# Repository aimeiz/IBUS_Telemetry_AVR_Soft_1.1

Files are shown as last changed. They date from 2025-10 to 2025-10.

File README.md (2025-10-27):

# IBUS_Telemetry_AVR_Soft_1.1
This is simple combo sensor for Flysky ADHDS2A RC systems.
Based on Arduino MiniPro 5V 16MHz , NEO6M-7M-GPS and BME280 5V modules.
It communicates with Flysky receivers i.e FS-IA6b via Sebsor IBUS port.
Prototype has been built on doublesided prototype PCB.
Elements are mounted on both side, to assure compact sensor sizes.
I attach also schematics, PCB design (Eagle / Fusion), and cabinet stls for 3D print and Gerber files to make easy order for PCB's
For more modern GPS module i.e 8M PCB require minor patching - modules have different pinout.
Major issue is, that IBUS libraries i found and used for this project, do not support block send of GPS data, so popular FX-i6X transmitter doesn't display GPS data correctly.
I am using Radiomaster TX16S 4in1 with EbgeTX 2.11.3 open source firmware and it works well. So I attach GpsInfo widget for tis system.
TO DO - electronics has additional servo port to connect to free servo channel or IBUS servo port to update Home position and altitude. It is not implement in current firmware version.
Yhe easiest way is to use servo channel, but also possible to decode IBUS servo port signal to extract servo channel which is even not covered by receiver's servo terminal.
Feel free to use, fork and modify.

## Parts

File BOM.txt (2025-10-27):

Partlist exported from C:/Users/sp5io/AppData/Local/Temp/Neutron/ElectronFileOutput/13544/sch-48b16895-195c-4b96-89e7-4660fa59e146/Bez nazwy.sch at 10/27/2025 7:45 AM

Part     Value                Device                Footprint Name          Detailed Description                                                          CATEGORY  MANUFACTURER MPN OPERATING_TEMP PART_STATUS POPULARITY ROHS_COMPLIANT SERIES SPICEPREFIX SUB-CATEGORY THERMALLOSS TYPE VOLTAGE_RATING
B1       ARDUINO_PRO_MINI     ARDUINO_PRO_MINI      ARDUINO_PRO_MINI        SparkFun Pro Mini                                                                                                                                                                                                            
C1       4700uF/6.3V          C-POL_RADIAL-11MM-DIA CAPPRD508W65D1000H1100B Capacitor Polarised - Generic                                                 Capacitor                                                                                                                                      
C2       100nF                C-US025-024X044       C025-024X044            CAPACITOR, American symbol                                                                                                          17                               C                                                       
DEBUG                         PINHD-1X2             1X02                    PIN HEADER                                                                                                                          98                                                                                       
HOME_SET                      PINHD-1X3             1X03                    PIN HEADER                                                                                                                          92                                                                                       
IBUS_IN                       PINHD-1X3             1X03                    PIN HEADER                                                                                                                          92                                                                                       
IBUS_OUT                      PINHD-1X3             1X03                    PIN HEADER                                                                                                                          92                                                                                       
R1       4.7K                 R-EU_0204/5           0204/5                  RESISTOR, European symbol                                                                                                           35                               R                                                       
R2       4.7K                 R-EU_0204/5           0204/5                  RESISTOR, European symbol                                                                                                           35                               R                                                       
R3       180K                 R-EU_0204/5           0204/5                  RESISTOR, European symbol                                                                                                           35                               R                                                       
R4       10K                  R-EU_0204/5           0204/5                  RESISTOR, European symbol                                                                                                           35                               R                                                       
U1       BME280_MODULE_5V_STD BME280_MODULE_5V_STD  BME280_MODULE_5V        BME280/BMP280 5 V I2C breakout (VIN,GND,SCL,SDA), 15×11 mm, outline tDocu(51)                                                                                                                                                
U2       NEO6M_GPS_MODULE     NEO6M_GPS_MODULE      NEO6M_GPS_MODULE                                                                                                                                                                                                                                     
UPLOAD                        PINHD-1X2             1X02                    PIN HEADER                                                                                                                          98                                                                                       
VOLTAGE                       PINHD-1X1             1X01                    PIN HEADER                                                                                                                          64

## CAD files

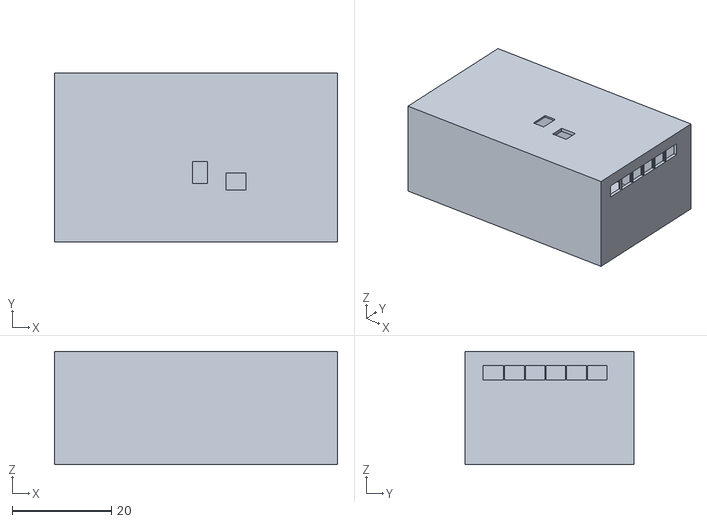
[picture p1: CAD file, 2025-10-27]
Cabinet_55x33.stl
57.0 x 34.0 x 22.8

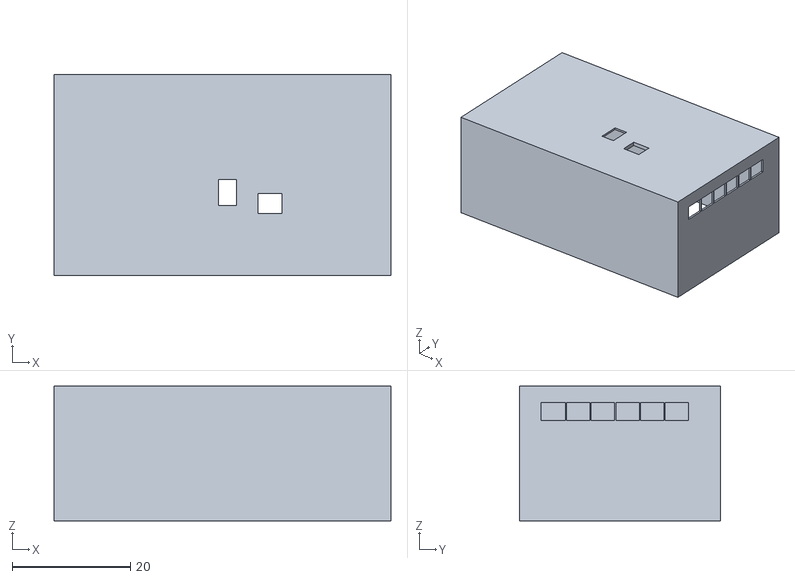
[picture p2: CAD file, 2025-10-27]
Cover_55x33.stl
57.0 x 34.0 x 22.8

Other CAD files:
IBUS GPS BME Sensor v6.f3d

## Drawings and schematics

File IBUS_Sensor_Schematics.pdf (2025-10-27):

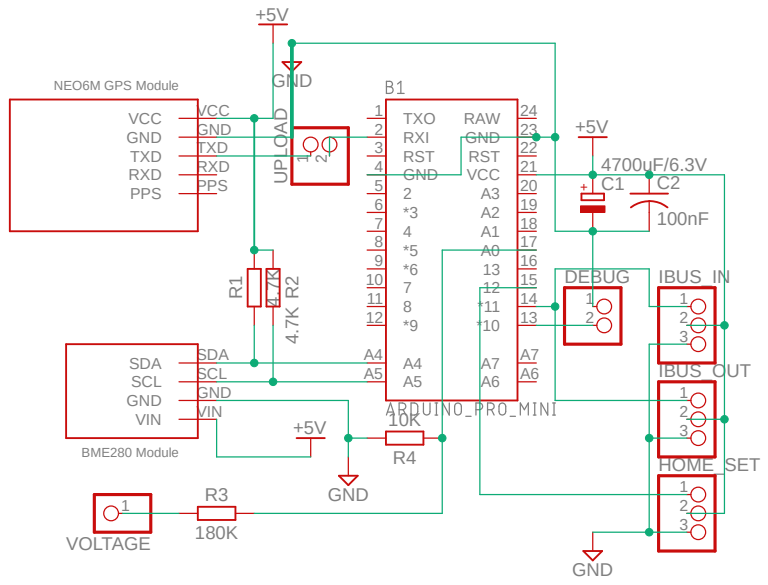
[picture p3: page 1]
GND; 20 GND 4; 23 RAW; RST 3; RST; 22 RXI 2; TXO 1; VCC; VIN; VIN GND; GND SCL; SCL SDA; SDA; BME280 Module; R² UPLOAD 1; DEBUG 1 2; IBUS_IN 1 2 3; IBUS_OUT 1 2 3; HOME_SET 1 2 3; VOLTAGE; TXD; RXD; PPS; NEO6M GPS Module

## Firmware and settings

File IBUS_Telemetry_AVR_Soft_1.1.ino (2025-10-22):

/*IBUS Combo sensor based on NEO GPS, BPS280 sensor and Arduino AVR Atmega328P module by Aimeiz 2025/10
 * Based on IBUSTelemetry library by adis1313 https://github.com/SoluTekSteam/75_IbusTelemetry_adis1313_iBUSTelemetry-Arduino
 * GPS and debug / upload serial port is shared, so assure jumper to disconnect GPS Tx pin from Arduino RX0 pin to upload code
 * DBUG Serial printous are activated by setting DEBUG_PIN to LOW state. Disable DEBUG for normal opiretion. 
 * Pullup I2C SDA, SCL lines by 4.7k resistors.
 * Install >= 1000uF/ 6.3V Low ESR capacitor on 5V supply I used 4700uF / 6.3V, and 0.1uF also, to block interferences.
 * 
 * Current version doesn't display GPS data properly on Flysky I6X transmitter due to old data format, but works well on EdgeTX (RADIOMASTER TX16S
 * See attached GpsInfo widget for EdgeTX 
 */
 
#define VERSION "IBUS Telemetry V1.1 20251018 Arduino Pro Mini ATMEGA328 Mini 5V 16MHz, BMe/BMP280 5VV NEO-6M-7M-GPS 5V"
//#define VERSION "IBUS Telemetry V1.1 20251018 Arduino Nano ATMEGA328 Mini 5V 16MHz, BMe/BMP280 5V NEO-6M-7M-GPS 5V"

#include "iBUSTelemetry.h" https://github.com/SoluTekSteam/75_IbusTelemetry_adis1313_iBUSTelemetry-Arduino
#include <Wire.h>
#include <BME280I2C.h>          // https://github.com/Seeed-Studio/Grove_BME280
#include <TinyGPS++.h>          // https://github.com/mikalhart/TinyGPSPlus

#define IBUS_PIN 11             // pin RX IBUS (PCINT na Nano)
iBUSTelemetry telemetry(IBUS_PIN);

BME280I2C bme;                  // default addr 0x76
float temperature = 0, pressure = 0, altitude = 0;
float basePressure = 1013.25;

// --- Hardware state flags ---
bool bmeAvailable = false;
bool bmeHasHumidity = false;
bool gpsAvailable = false;
uint8_t bmeType = 0;   // 0=none, 1=BMP280, 2=BME280, 3=unknown

#define gpsSerial Serial
TinyGPSPlus gps;

#define VOLTAGE_PIN A0
#define VOLTAGE_DIVIDER 23.974

#define DEBUG_PIN 10             // podłączony do GND = włącz debug
#define UPDATE_INTERVAL 500
uint32_t prevMillis = 0;

double homeLat = 0, homeLon = 0, homeAlt = 0;
bool homeSet = false;

void setup()
{
  pinMode(DEBUG_PIN, INPUT_PULLUP);
  gpsSerial.begin(9600);
  delay(2000); // czekaj na stabilizację zasilania
  if (digitalRead(DEBUG_PIN) == LOW) {
    Serial.println(F(VERSION));
  }
  Wire.begin();
  telemetry.begin();

  // Czujniki 2B
  telemetry.addSensor(IBUS_MEAS_TYPE_TEM);         // 0x01 1
  telemetry.addSensor(IBUS_MEAS_TYPE_EXTV);        // 0x03 2
  telemetry.addSensor(IBUS_MEAS_TYPE_GPS_STATUS);  // 0x0B 3
  telemetry.addSensor(IBUS_MEAS_TYPE_GPS_DIST);    // 0x14 4
  telemetry.addSensor(IBUS_MEAS_TYPE_CMP_HEAD);    // 0x08 5
  telemetry.addSensor(IBUS_MEAS_TYPE_GROUND_SPEED);// 0x13 6
  //  telemetry.addSensor(IBUS_MEAS_TYPE_GPS_FULL);	    //0xfd 7
  // Czujniki 4B
  telemetry.addSensor(IBUS_MEAS_TYPE_ALT);         // 0x83 (4B) 7
  telemetry.addSensor(IBUS_MEAS_TYPE_GPS_LAT);     // 0x80  8
  telemetry.addSensor(IBUS_MEAS_TYPE_GPS_LON);     // 0x81  9
  telemetry.addSensor(IBUS_MEAS_TYPE_GPS_ALT);     // 0x82  10
  telemetry.addSensor(IBUS_MEAS_TYPE_HEADING);     // 0x7d Heading 11
  telemetry.addSensor(IBUS_MEAS_TYPE_SPE);       // 0x7e Speed km/h 12
  telemetry.addSensor(IBUS_MEAS_TYPE_GPS_DIST);    // 0x14 13

  // --- Initialize BME/BMP sensor with retry limit ---
  const uint8_t maxRetries = 5;
  for (uint8_t i = 0; i < maxRetries; i++) {
    if (bme.begin()) {
      bmeAvailable = true;
      bme.read(pressure, temperature, altitude);
      basePressure = pressure;

      // Identify sensor model
      BME280::ChipModel model = bme.chipModel();
      if (model == BME280::ChipModel_BME280) {
        bmeType = 2;
        bmeHasHumidity = true;
      } else if (model == BME280::ChipModel_BMP280) {
        bmeType = 1;
        bmeHasHumidity = false;
      } else {
        bmeType = 3;
        bmeHasHumidity = false;
      }
      break;
    }
    delay(500);
  }

  // --- GPS detection (2 s timeout) ---
  uint32_t start = millis();
  while (millis() - start < 2000) {
    if (gpsSerial.available()) {
      if (gps.encode(gpsSerial.read())) {
        gpsAvailable = true;
        break;
      }
    }
  }

  // --- Debug report ---
  if (digitalRead(DEBUG_PIN) == LOW) {
    Serial.println();
    Serial.println(F("=== Hardware detection ==="));

    if (bmeAvailable) {
      if (bmeType == 2) {
        Serial.println(F("BME280 detected (pressure + temperature + humidity)"));
      } else if (bmeType == 1) {
        Serial.println(F("BMP280 detected (pressure + temperature only)"));
      } else {
        Serial.println(F("Unknown BME/BMP sensor model"));
      }

      Serial.print(F("Temperature: ")); Serial.print(temperature, 1); Serial.println(F(" °C"));
      Serial.print(F("Pressure: "));    Serial.print(pressure, 1);    Serial.println(F(" hPa"));

      if (bmeHasHumidity) {
        float humidity = NAN;
        bme.read(pressure, temperature, humidity, BME280::TempUnit_Celsius, BME280::PresUnit_hPa);
        if (!isnan(humidity)) {
          Serial.print(F("Humidity: ")); Serial.print(humidity, 1); Serial.println(F(" %"));
        }
      }
    } else {
      Serial.println(F("No BME/BMP sensor detected"));
    }

    Serial.print(F("GPS: "));
    Serial.println(gpsAvailable ? F("detected (NEO-6M/7M OK)") : F("not detected"));

    Serial.println(F("=========================="));
    Serial.println();
  }
}

void loop()
{
  while (gpsSerial.available()) {
    gps.encode(gpsSerial.read());
  }

  updateValues();
  telemetry.run();
}

void updateValues()
{
  uint32_t currMillis = millis();
  if (currMillis - prevMillis < UPDATE_INTERVAL) return;
  prevMillis = currMillis;

  // --- BME/BMP ---
  float relAltitude = 0.0;
  if (bmeAvailable) {
    bme.read(pressure, temperature, altitude);
    relAltitude = 44330.0 * (1.0 - pow((pressure / basePressure), 0.1903));
  } else {
    temperature = 0;
    pressure = 0;
  }

  // --- Voltage ---
  float adc = analogRead(VOLTAGE_PIN);
  float voltage = (adc / 1023.0) * 5.0 * VOLTAGE_DIVIDER;

  // --- GPS position and values ---
  uint8_t fix = gps.location.isValid() ? 3 : 0;
  uint8_t sats = gps.satellites.value();
  double lat = gps.location.lat();
  double lon = gps.location.lng();
  double gpsAlt = gps.altitude.meters();
  double speedKmph = gps.speed.kmph();
  double speedMps = gps.speed.mps();
  double course = gps.course.deg();

  // Home position
  if (!homeSet && gps.location.isValid()) {
    homeLat = lat;
    homeLon = lon;
    homeAlt = gpsAlt;
    homeSet = true;
  }

  // Distance, Heading, Relative altitude
  float distance = 0, heading = 0, gpsRelAlt = 0;
  if (homeSet && gps.location.isValid()) {
    distance = gps.distanceBetween(lat, lon, homeLat, homeLon); // meters
    heading = gps.courseTo(homeLat, homeLon, lat, lon);         // degrees
    gpsRelAlt = gpsAlt - homeAlt;
  }

  // --- TELEMETRY ---
  telemetry.setSensorValueFP(1, temperature);                 // TEM
  telemetry.setSensorValue(2, (uint16_t)(voltage * 100));     // EXT_V
  telemetry.setSensorValue(3, telemetry.gpsStateValues(fix, sats)); // GPS_STATUS
  telemetry.setSensorValue(4, (uint16_t)distance);             // GPS_DIST
  telemetry.setSensorValue(5, (uint16_t)heading);              // CMP_HEAD
  telemetry.setSensorValueFP(6, speedMps);                     // GROUND_SPEED
  telemetry.setSensorValueFP(7, relAltitude);                  // ALT (BME280)
  telemetry.setSensorValue(8, lat * 1e7);                      // GPS_LAT
  telemetry.setSensorValue(9, lon * 1e7);                      // GPS_LON
  telemetry.setSensorValue(10, gpsAlt);                        // GPS_ALT
  telemetry.setSensorValue(11, (uint16_t)course);              // HEADING
  telemetry.setSensorValue(12, (uint16_t)(speedKmph * 100));   // SPEED km/h
  telemetry.setSensorValue(13, (uint16_t)distance);             // GPS_DIST

  // --- DEBUG ---
  if (digitalRead(DEBUG_PIN) == LOW) {
    Serial.print(F("Tmp1: ")); Serial.print(temperature); Serial.print(F(" C"));
    Serial.print(F(", A3: ")); Serial.print(voltage); Serial.print(F(" V"));
    Serial.print(F(", Pres: ")); Serial.print(pressure); Serial.print(F(" hPa"));
    Serial.print(F(", Sats: ")); Serial.print(sats);
    Serial.print(F(", Fix: ")); Serial.print(fix);
    Serial.print(F(", Dist: ")); Serial.print(distance); Serial.print(F(" m"));
    Serial.print(F(", Hdg: ")); Serial.print(heading); Serial.print(F(" deg (to home)"));
    Serial.print(F(", Course: ")); Serial.print(course); Serial.print(F(" deg (absolute)"));
    Serial.print(F(", SpeedMps: ")); Serial.print(speedMps); Serial.print(F(" m/s"));
    Serial.print(F(", SpeedKmph: ")); Serial.print(speedKmph); Serial.print(F(" km/h"));
    Serial.print(F(", RelAlt: ")); Serial.print(relAltitude); Serial.print(F(" m (BME280)"));
    Serial.print(F(", GPSRelAlt: ")); Serial.print(gpsRelAlt); Serial.print(F(" m"));
    Serial.print(F(", Lat: ")); Serial.print(lat, 7);
    Serial.print(F(", Lon: ")); Serial.print(lon, 7);
    Serial.print(F(", GPSAlt: ")); Serial.print(gpsAlt); Serial.print(F(" m"));
    Serial.print(homeSet ? F(", Home SET") : F(", Home NOT SET"));
    Serial.print(F(", homeLat: ")); Serial.print(homeLat, 7);
    Serial.print(F(", homeLon: ")); Serial.print(homeLon, 7);
    Serial.print(F(", homeAlt: ")); Serial.print(homeAlt); Serial.print(F(" m"));
    Serial.println();
  }
}

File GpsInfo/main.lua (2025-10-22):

--[[
GpsInfo widget for EdgeTX (text-only, half screen)
Works with sensors: Sats, Dist, Hdg, GSpd, GPS, GAlt, ASpd (optional)
Safely handles GPS as a table (lat/lon) or nil.
]]

local LABEL_X = 5
local VALUE_X = 100
local LINE_H  = 15
local TITLE_Y = 5
local START_Y = 30

-- Safe numeric read: returns number (or 0 if table/nil)
local function num(sensorName)
  local v = getValue(sensorName)
  return (type(v) == "number") and v or 0
end

-- Safe GPS read: returns table {lat=..., lon=..., fix=...} or nil
local function readGpsTable()
  local v = getValue("GPS")
  if type(v) == "table" then
    -- Common field names used in EdgeTX/OpenTX
    local lat = v.lat or v.latitude
    local lon = v.lon or v.longitude
    local fix = v.fix or v.gpsFix or nil
    return { lat = lat, lon = lon, fix = fix }
  end
  return nil
end

-- Fix text from fix code or sats fallback
local function fixTextFrom(gpsFix, sats)
  if type(gpsFix) == "number" then
    if gpsFix == 0 then return "NO FIX"
    elseif gpsFix == 2 then return "2D FIX"
    elseif gpsFix == 3 then return "3D FIX"
    else return tostring(gpsFix) end
  end
  -- Fallback by satellites count when fix code is unavailable
  if sats >= 6 then return "3D FIX"
  elseif sats >= 4 then return "2D FIX"
  else return "NO FIX" end
end

local function create(zone, options)
  return { zone = zone, options = options }
end

local function update(widget, options)
  widget.options = options
end

local function background(widget) end

local function drawLabelValue(y, label, value)
  lcd.drawText(LABEL_X, y, label)
  lcd.drawText(VALUE_X, y, value)
end

local function refresh(widget)
  lcd.clear()

  -- Read core sensors
  local sats    = num("Sats")
  local alt     = num("GAlt")
  local gspd    = num("GSpd")
  local vspeed  = num("VSpd")   -- may be 0 / missing
  local heading = num("Hdg")
  local dist    = num("Dist")
  local aspd    = num("ASpd")   -- optional (pitot); 0 if absent

  -- Read GPS table (lat/lon + optional fix)
  local gps = readGpsTable()
  local fixTxt = fixTextFrom(gps and gps.fix, sats)

  -- Title
  lcd.drawText(LABEL_X, TITLE_Y, "GPS Telemetry", INVERS)

  local y = START_Y
  drawLabelValue(y,   "Fix:",          fixTxt);                    y = y + LINE_H
  drawLabelValue(y,   "Satellites:",   string.format("%d", sats)); y = y + LINE_H

  -- Coordinates if available
  if gps and gps.lat and gps.lon then
    drawLabelValue(y, "Latitude:",     string.format("%.6f", gps.lat)); y = y + LINE_H
    drawLabelValue(y, "Longitude:",    string.format("%.6f", gps.lon)); y = y + LINE_H
  end

  drawLabelValue(y,   "Altitude:",     string.format("%.1f m",   alt));     y = y + LINE_H
  drawLabelValue(y,   "Speed:",        string.format("%.1f km/h", gspd));   y = y + LINE_H
  drawLabelValue(y,   "VSpeed:",       string.format("%.1f m/s", vspeed));  y = y + LINE_H
  drawLabelValue(y,   "Heading:",      string.format("%.0f°",    heading)); y = y + LINE_H
  drawLabelValue(y,   "Distance:",     string.format("%.0f m",   dist));    y = y + LINE_H

  if aspd > 0 then
    drawLabelValue(y, "AirSpeed:",     string.format("%.1f km/h", aspd));   y = y + LINE_H
  end
end

return {
  name = "GpsInfo",
  options = {},
  create = create,
  update = update,
  background = background,
  refresh = refresh
}
